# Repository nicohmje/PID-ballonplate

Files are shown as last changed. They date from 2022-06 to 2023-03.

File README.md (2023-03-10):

# Using a PID algo and Computer Vision to stabilize a ping-pong ball on a moving plane

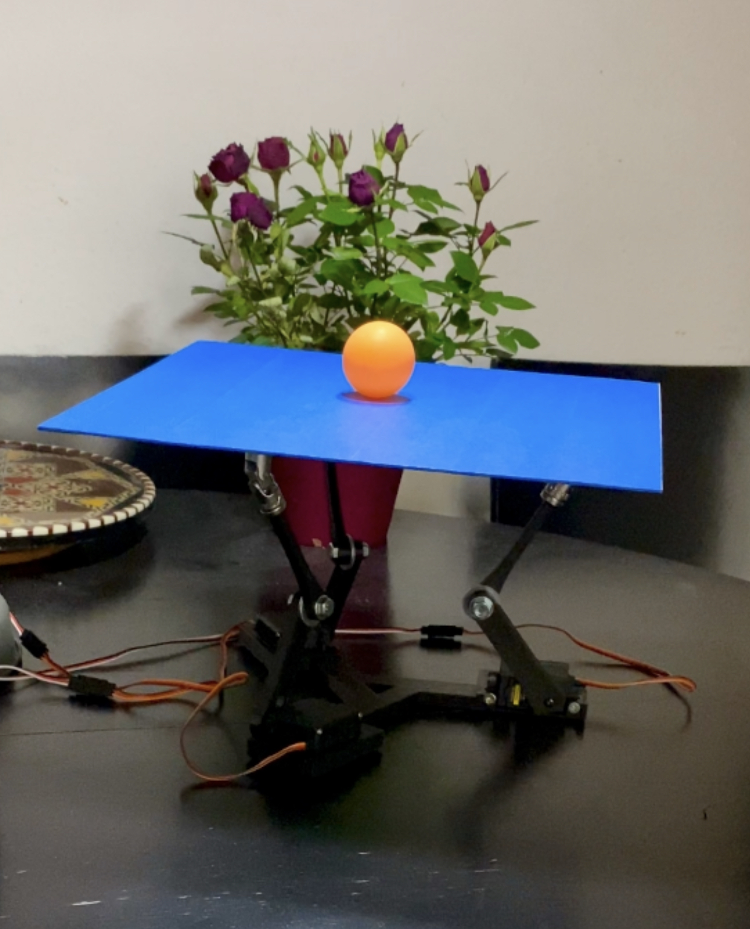
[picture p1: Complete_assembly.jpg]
the complete assembly


A relatively straightforward project using a Raspberry Pi, three servos and a 3D printed structure.

[SEE IT IN ACTION!](https://www.reddit.com/r/3Dprinting/comments/vbh1qf/3d_printed_all_the_parts_almost_for_this_fun/)

## Principle behind the project: 

1. A Pi camera tracks the position of the ball, using OpenCV. A mask is first applied separating the orange color of the ball from the rest. The mask is then eroded twice, blurred, and finally a 'smallest enclosing circle' command returns the radius and the center position.

2. This information is then filtered by radius. If it is part of the range of radii that the ball is expected to have, the program calculates the error between the position of the ball and the center of the plate. Three errors total are calculated, one for each servos' line of action.

3. These three errors are then input in the three PID Controllers, including past errors and past derivatives. The PID Controllers then output a change of angle for each servo, which is first normalized against computing time to account for small variations, and then sent using AdaFruit's servo library to the motors. 

## Improvements / Failures

My current platform is unstable at best, and requires constant recalibration (Done through the GUI); a more stable platform could be obtained with a better interface between the arms. Ball bearings could be used to further smoothen the motion of the platform, and more drastically three more servos could be added for a full on Stewart platform. At this scale however with this level of precision, the current platform is suitable enough. 

One could also use Dynamixel Servos for a more accurate position control, although this would significantly increase the price of the whole assembly. 

## Parts list : 

- Raspberry Pi 4b 8 gb
- Pi Camera V2
- Adafruit Camera cable extension
- Three DIYMORE Full metal servos
- Waveshare Servo HAT
- Pimoroni Fan Shim
- Three Dexter Cardan Joints (Universal joints)

The rest of the parts are 3D printed. 

Part selection really doesn't matter that much apart from the RPi and the PiCamera. Use what is available to you for a fair price, and adapt the parts to your needs. 

## Want to replicate this project yourself ? 

Great idea! If you need any help, feel free to shoot me a message on reddit (/u/parisiancyclist) or Instagram (@nicohmje). You can also directly contact me through GitHub. 

The STL Files folder includes the necessary parts for this project. These should be adapted to your parts and specific setup, and should only serve as a reference. The 3MF Files folder includes the prototypes too, if you want a deeper, in-depth look at the projects evolution.

Happy building!

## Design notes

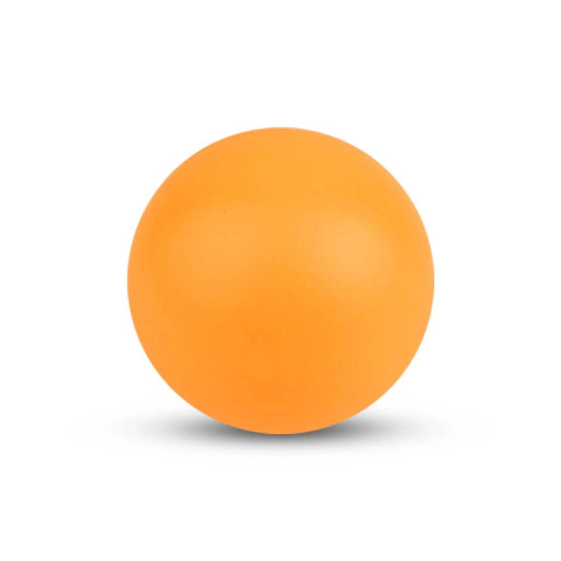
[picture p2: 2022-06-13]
ping-pong.jpg

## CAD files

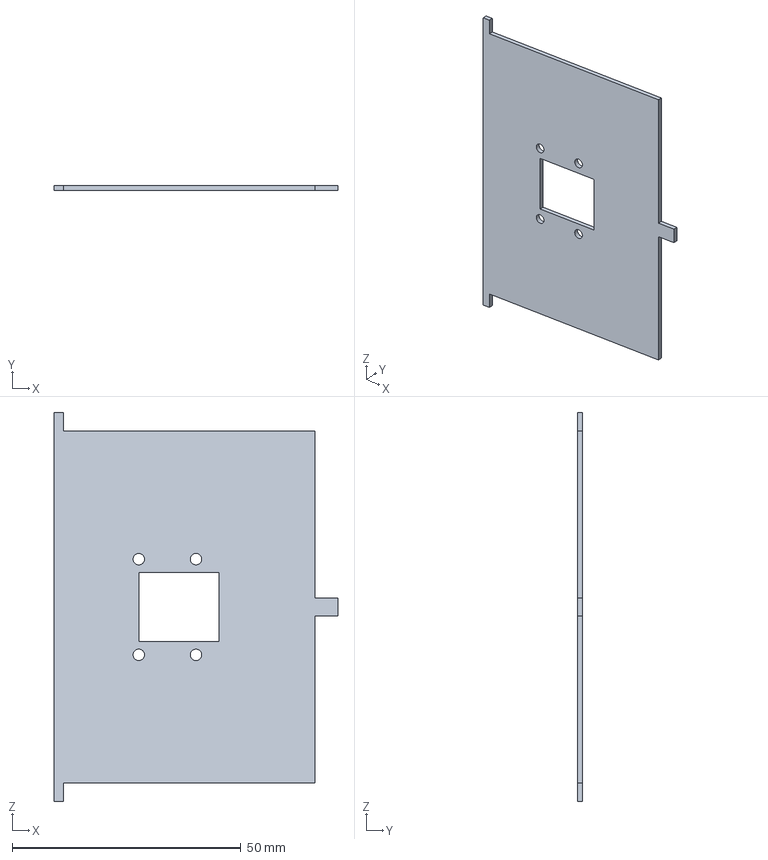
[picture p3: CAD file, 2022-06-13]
3MF Files/picamera_test2.3MF
62.0 x 1.20 x 85.0 mm

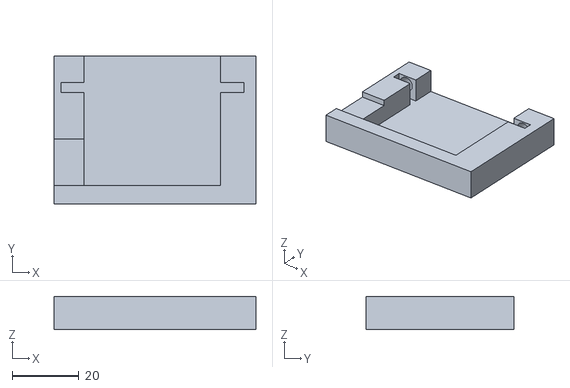
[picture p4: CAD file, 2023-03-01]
STL_Files/Servo_bracket_fit_test.stl
60.7 x 44.5 x 10.0

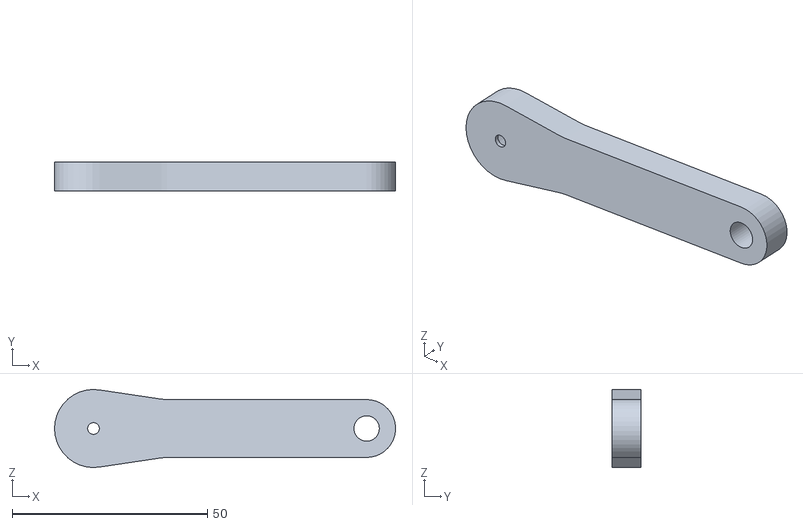
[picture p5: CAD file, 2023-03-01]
STL_Files/Arm1.STL
87.4 x 7.50 x 20.0

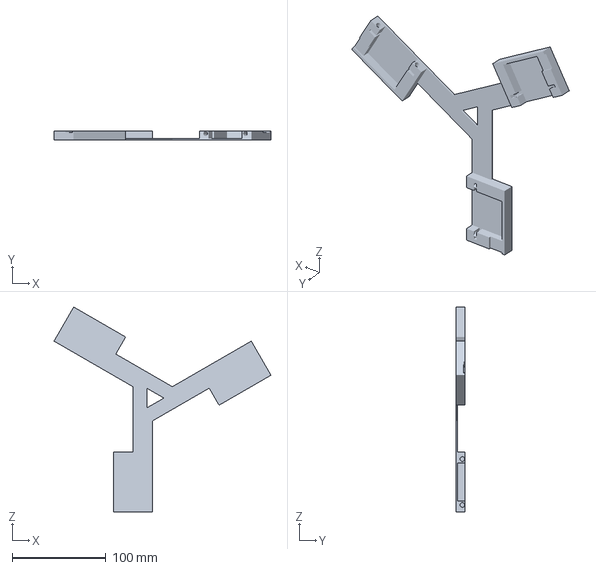
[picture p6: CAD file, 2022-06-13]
3MF Files/Base_proto1.3MF
231.4 x 10.0 x 218.6 mm

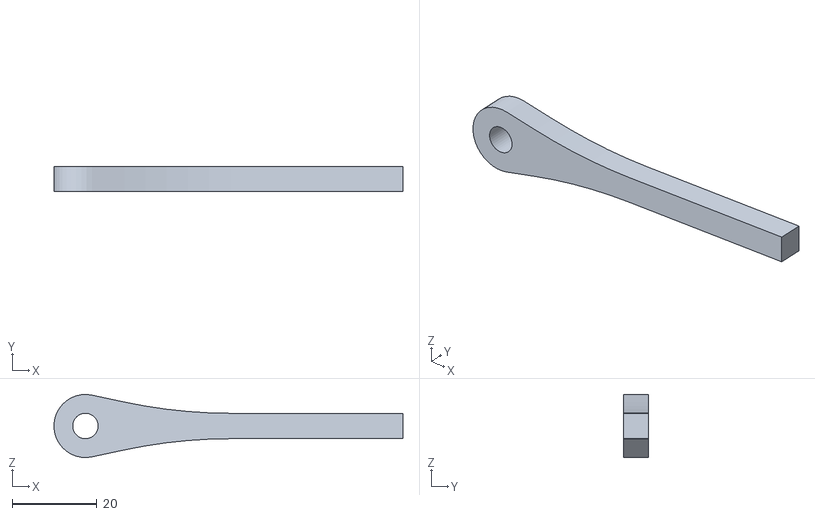
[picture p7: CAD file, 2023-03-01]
STL_Files/Arm2.stl
82.4 x 5.90 x 14.9

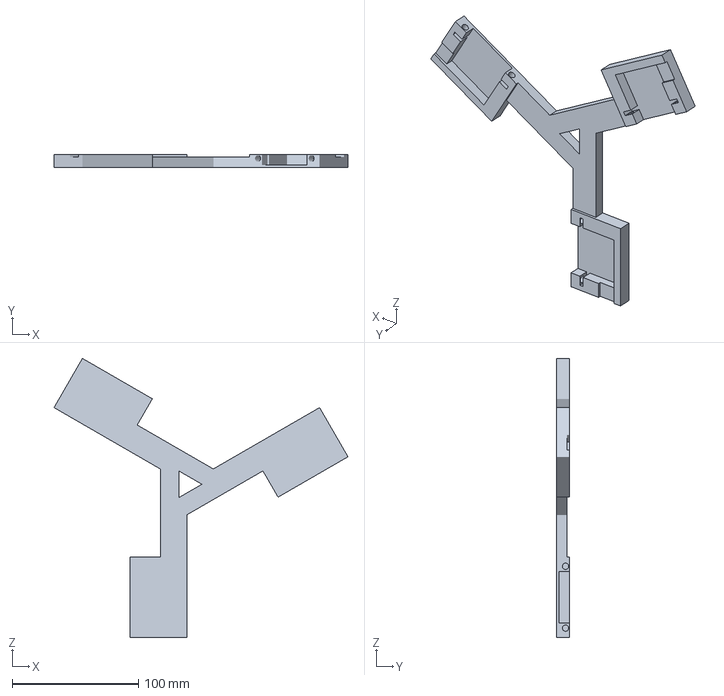
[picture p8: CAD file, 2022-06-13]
3MF Files/Base_proto2.3MF
232.9 x 10.0 x 221.2 mm

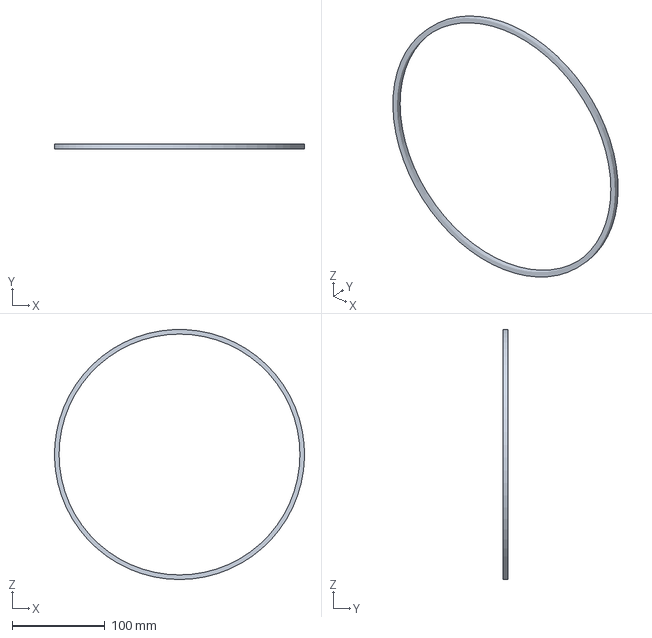
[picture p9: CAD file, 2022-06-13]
3MF Files/stencil.3MF
269.9 x 5.00 x 270.0 mm

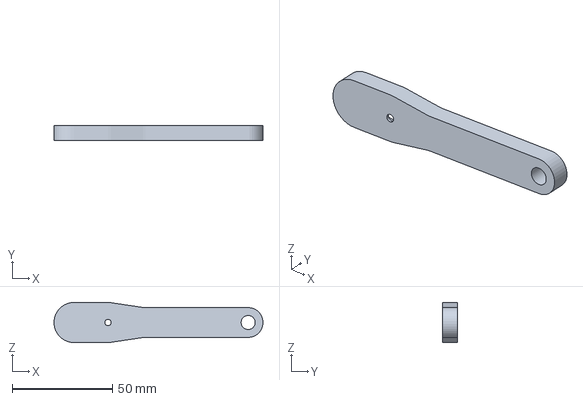
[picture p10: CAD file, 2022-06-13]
3MF Files/Arm_proto2.3MF
104.4 x 7.50 x 20.0 mm

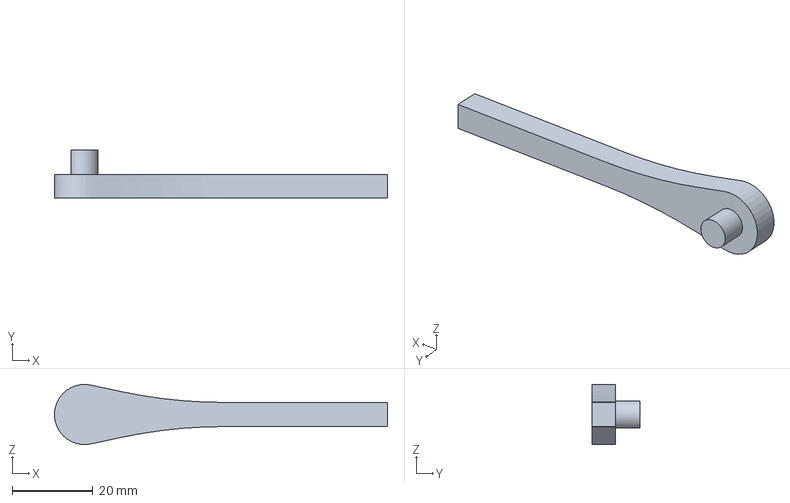
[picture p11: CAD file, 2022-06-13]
3MF Files/Arm2_proto2 3.3MF
82.4 x 12.0 x 14.9 mm

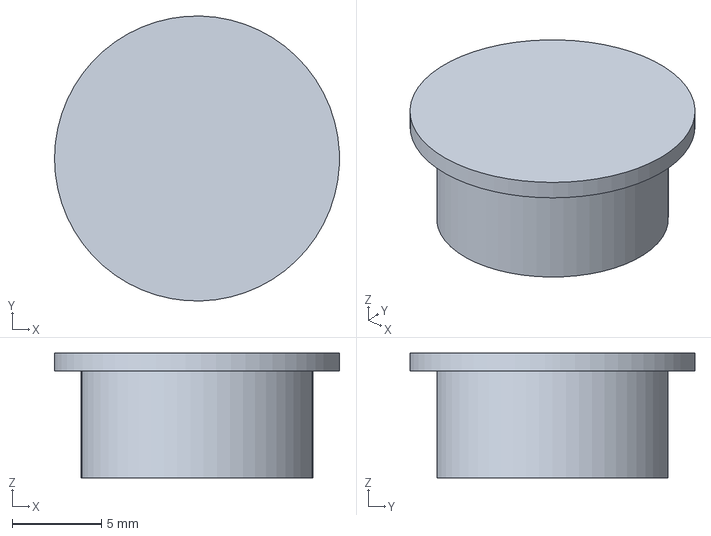
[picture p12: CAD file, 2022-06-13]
3MF Files/coupler.3MF
16.0 x 16.0 x 7.00 mm

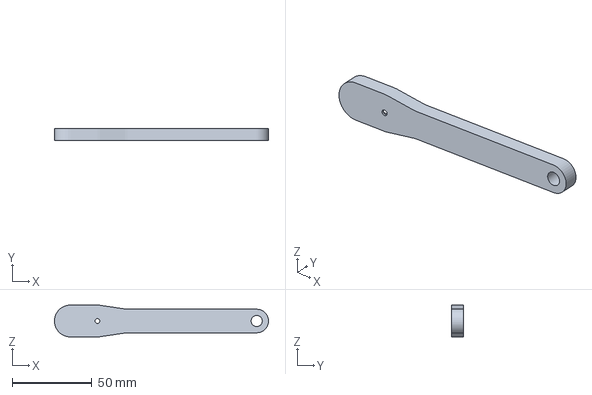
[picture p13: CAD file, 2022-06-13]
3MF Files/Arm_proto1.3MF
134.4 x 7.50 x 20.0 mm

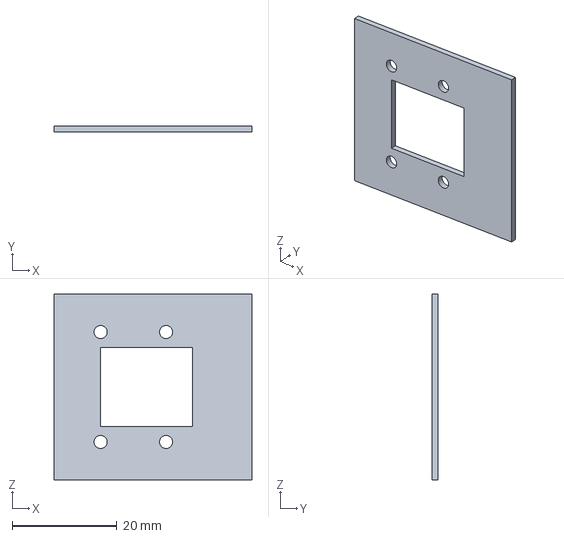
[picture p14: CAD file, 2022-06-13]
3MF Files/picamera_test.3MF
37.8 x 1.20 x 35.5 mm

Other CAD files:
3MF Files/Servo_bracket_proto2.3MF
STL_Files/Base.stl
3MF Files/Arm_proto3_1.3MF
3MF Files/Arm_proto3_2.3MF
3MF Files/Arm2_proto2 2.3MF
3MF Files/Arm_proto3_3.3MF
3MF Files/Arm2_proto1.3MF
3MF Files/Arm2_proto2.3MF
3MF Files/Arm2_proto3.3MF
3MF Files/PLATEAU.3MF
3MF Files/Servo_bracket_proto1.3MF
3MF Files/test_link.3MF

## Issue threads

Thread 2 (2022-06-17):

what is the model of the servo you used?

obstaclecourse, 2022-06-17:
thanks for the share!
in evaluating gathering the parts to make this, what model servo did you get from diymore and what's it's voltage?

nicohmje, 2023-01-14:
This is the amazon link to the servos I used : https://www.amazon.fr/dp/B09WQYPP17/
The model should not matter much.

Closed 2023-01-14.

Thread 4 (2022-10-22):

Just a question

915-Narita-Andrei, 2022-10-22:
Hello! First of all great job! I was very excited about your project and I also wanted to try it out. Please, could you send me the links of what you bought for this project? Especially for Three DIYMORE Full metal servos, Waveshare Servo HAT, Three Dexter Cardan Joints (Universal joints). I will be very grateful to you! Many thanks and keep up the good work!

nicohmje, 2022-10-22:
Hello, glad to hear you’re talking on this project! As for product links, if you’re not in France it wouldn’t be a good deal. The servos and cardan joints are the most generic thing ever, you should just look locally for something equivalent! The servo HAT was also something I bought because it was available in a shop near me. Here are the product links if you want the specs: Waveshare Servo Driver Hat Expansion Board Compatible with Raspberry Pi 12-Bit I2C Controlled Straight Pinheader Up to 16-Channel Servo/PWM Outputsamazon.frdiymore 6 pièces Servomoteur numérique à Engrenages en métal Version améliorée Servo de Couple à Grande Vitesse en cuivre Complet pour RC Hélicoptère Avion Voiture Bateau Robot Contrôleuramazon.frhttps://www.leroymerlin.fr/produits/outillage/outillage-a-main/cle/douille/cardan-chrome-vanadium-dexter-diam-15-mm-65996021.htmlLet me know if you need any other information! Cheers,Nicolas H. Sent from my iPhoneOn 22 Oct 2022, at 13:38, Andrei Narita ***@***.***> wrote:
Hello! First of all great job! I was very excited about your project and I also wanted to try it out. Please, could you send me the links of what you bought for this project? Especially for Three DIYMORE Full metal servos, Waveshare Servo HAT, Three Dexter Cardan Joints (Universal joints). I will be very gratefull to you! Many thanks and keep up the good work!

—Reply to this email directly, view it on GitHub, or unsubscribe.You are receiving this because you are subscribed to this thread.Message ID: ***@***.***>

Closed 2023-01-14.

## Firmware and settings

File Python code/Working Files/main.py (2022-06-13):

import numpy as np 
import cv2 as cv
import time
import tkinter as tk
from adafruit_servokit import ServoKit

#Initialize the three servos
kit = ServoKit(channels = 16)
kit.servo[0].set_pulse_width_range(500, 2500) #Very important
kit.servo[1].set_pulse_width_range(500, 2500) #Very important
kit.servo[2].set_pulse_width_range(500, 2500) #Very important

#Center coordinates
center_x = 250
center_y = 250  

prevX = 0
prevY = 0 

#Min and max angles of each motor
min_motor = np.array([85,85,77])
max_motor = np.array([175,175,165])

#Sets the angle of the motors to the chosen values
def set_angle():
    global initial_angle
    initial_angle[0] = e0.get()
    initial_angle[1] = e1.get()
    initial_angle[2] = e2.get()
    initialPos()

initial_angle = np.array([124,120,111]) #These depend on how level the surface is

#Initial position of the motors
def initialPos():
    kit.servo[0].angle = int(e0.get())
    kit.servo[1].angle = int(e1.get())
    kit.servo[2].angle = int(e2.get())

#Initialize the capture 
cap = cv.VideoCapture(0)

#Moves the motor according to the instructions given by the PID
def move_motors(pid):
    for i in np.arange(0,3,1):
        angle = initial_angle[i] - (pid[i]/150.0 * 20)
        angle = np.floor(angle)
        if angle > max_motor[i]:
            print("angle limit high")
            angle = max_motor[i]
        if angle < min_motor[i]:
            print("angle limit low")
            angle = min_motor[i]
        kit.servo[i].angle = angle 

#Finds the ball's center
def ballFinder():
    ret, frame = cap.read()
    result = (0,0)
    if ret:
        frame = frame[:, 93:550, :]
        hsv = cv.cvtColor(frame, cv.COLOR_BGR2HSV)
        lower_value = np.array([00,80,100])
        higher_value = np.array([50,255,255])
        mask = cv.inRange(hsv, lower_value, higher_value)
        mask = cv.blur(mask,(6,6))                        
        mask = cv.erode(mask, None, iterations=2)         
        mask = cv.dilate(mask, None, iterations=2)        
        contours, _ = cv.findContours(mask, cv.RETR_TREE, cv.CHAIN_APPROX_SIMPLE)
        for cnt in contours:
            area = cv.contourArea(cnt)
            if area > 1500:
                (x,y), radius = cv.minEnclosingCircle(cnt)
                x = int(x)
                y = 480 - int(y) #In images, y=0 is on top, not on the bottom 
                radius = int(radius)
                if radius > 20:
                    result = (x,y)
    return(result)

#This allows you to properly place the plate beneath the camera
def CenterCalibration():
    for i in np.arange(0,150):
        ret, frame = cap.read()
        if ret:
            frame = frame[:,93:550,:]
            cv.circle(frame,(center_x,center_y),3,[255,130,130],3)
            cv.imshow("Calibration", frame)
            cv.waitKey(1)
        else:
            pass
           
        
started = False
#GUI and looping
def start_program():
    global started,i
    set_values()
    reset_values()
    if started:
        start["text"] = "Start"
        started = False
    else:
        start["text"] = "Stop"
        started = True

errors = np.zeros(3)
pasterrors = np.zeros(3)
#Calculates the error for each line of action of each servo
def get_errors(x,y):
    global center_x, center_y, errors, pasterrors
    print(center_x, center_y)
    pasterrors = np.copy(errors)
    errors[0] = y - center_y  
    errors[1] = (np.sqrt(3)*(x-center_x) + (center_y - y))/2.0
    errors[2] = (np.sqrt(3)*(center_x - x) + (center_y - y))/2.
    #errors[abs(errors - pasterrors) > 40] = pasterrors[abs(errors - pasterrors) > 40]
    #print(abs(errors - pasterrors))
    print(errors[0])

lastderivative = 0 
lastlastderivative = 0 
integral = 0
derivative = 0 
pid = 0
#Calculates the PID and normalizes it based on computation time 
def pid_control(compT):
    global errors, pasterrors
    global lastderivative, lastlastderivative, derivative
    global Kp, Ki, Kd, Ka
    global integral
    global lastpid
    global computation_time
    #output == Kp * error + Ki * integral + Kd * derivative 
    global pid 
    if np.all(errors > 10):
        integral += errors * 0.5 
    else:
        integral = 0
    Kd_normalized = np.copy(Kd) / (compT/np.mean(computation_time))
    Ka_normalized = np.copy(Ka) * (compT/np.mean(computation_time))
    Kp_normalized = np.copy(Kp)
    Kp_normalized[np.abs(errors) < 20] = Kp_normalized[np.abs(errors) < 20] * 0.5
    lastlastderivative = np.copy(lastderivative)
    lastderivative = np.copy(derivative)
    derivative = (errors - pasterrors)
    #print("SUM",np.sum(abs(derivative)))
    if np.sum(abs(derivative)) < 10:
        Kd_normalized = Kd_normalized *  (0.1*(np.sum(abs(derivative))))
    elif np.sum(abs(derivative)) > 20:
        Kd_normalized = Kd_normalized * 1.1
    if np.all(np.abs(derivative) < 0.5):
        Kd_normalized = 0
    lastpid = pid
    pid = Kp_normalized * errors + Ki * integral  + Kd_normalized * (((5*derivative) + (3*lastderivative) + (2*lastlastderivative))/10.0) + Ka_normalized * (((derivative - lastderivative) + (lastderivative - lastlastderivative))/2.0) 
    return pid 


Kp = np.zeros(3)
Kd = np.zeros(3)
Ka = np.zeros(3)
Ki = np.zeros(3)

#Resets the values, if the ball leaves the plate
def reset_values():
    global derivative, lastderivative, lastlastderivative, i
    global pasterrors, errors, pid
    derivative = 0
    lastderivative = 0
    lastlastderivative = 0 
    pid = 0
    i = 0
    print('successfully reset all values')

#sets the coefficients 
def set_values():
    global Kp, Ki, Kd, Ka
    i = int(motor_selector.get())
    if i == 3:  
        Kp[:] = p_slider.get() / 10.0 
        Ki[:] = i_slider.get() / 10.0
        Kd[:] = d_slider.get()
        Ka[:] = a_slider.get()
    else:
        Kp[i] = p_slider.get() / 10.0 
        Ki[i] = i_slider.get() / 10.0
        Kd[i] = d_slider.get()
        Ka[i] = a_slider.get()
    print(Kp, Ki, Kd, Ka)

t = 0 
#Refreshes the 'ball position' graph
def refresh(x, y):
    global t
    graphWindow.deiconify()
    graphCanvas.create_oval(x,y,x,y, fill="#b20000", width=4)
    graphCanvas.create_line(0,240,480,240, fill="#0069b5", width=2)
    graphCanvas.create_line(240,0,240,480, fill="#0069b5", width=2)
    if t >= 480:
        t = 0
        graphCanvas.delete("all")
        graphCanvas.create_line(0,240,480,240, fill="#0069b5", width=2)
        graphCanvas.create_line(240,0,240,480, fill="#0069b5", width=2)
        graphCanvas.create_oval(x,y,x+1,y, fill="#b20000")
    t += 4

computation_time = []
#Main loop
def main():
    global prevX, prevY, computation_time
    global center_x, center_y
    start_time = time.time()
    if started:
        x, y = ballFinder()
        #print("posiiton", x,y)
        if x != y != 0: 
            detected = True
            get_errors(x,y)
            compT = (time.time() - start_time)
            computation_time.append(compT)
            pid = pid_control(compT)  
            #print(pid[0])
            #print(compT / np.mean(computation_time))

            move_motors(pid) 
            prevX = x
            prevY = y
        else:
            initialPos()        
        refresh(x, y)
    lmain.after(1,main)

    
#GUI PART 

window = tk.Tk()
window.geometry("820x500")
window.title("Test ?")

p_slider = tk.Scale(window,  from_=0, to=15, orient="horizontal", label="Proportionnal", length=500, tickinterval=2.5, resolution=0.1)
p_slider.set(3)
p_slider.pack()
i_slider = tk.Scale(window,  from_=0, to=1, orient="horizontal", label="Integral", length=500, tickinterval=0.25, resolution=0.005)
i_slider.set(0)
i_slider.pack()
d_slider = tk.Scale(window,  from_=0, to=10, orient="horizontal", label="Derivative", length=500, tickinterval=10, resolution=0.1)
d_slider.set(6.2)
d_slider.pack()
a_slider = tk.Scale(window,  from_=0, to=10, orient="horizontal", label="Double Derivative", length=500, tickinterval=10, resolution=0.1)
a_slider.set(5.6)
a_slider.pack()

p_slider.place(x=250, y= 0)
i_slider.place(x=250, y= 100)
d_slider.place(x=250, y= 200)
a_slider.place(x=250, y= 300)

tk.Label(window, text="Motor0").place(x=00,y=20)
tk.Label(window, text="Motor1").place(x=00,y=50)
tk.Label(window, text="Motor2").place(x=00,y=80)


lmain = tk.Label(window)
lmain.pack()

graphWindow = tk.Toplevel(window)
graphWindow.title('Ball position')
graphCanvas = tk.Canvas(graphWindow,width=480,height=480)
graphCanvas.pack()

motor0 = tk.StringVar(window)
motor1 = tk.StringVar(window)
motor2 = tk.StringVar(window)
motor_select = tk.StringVar(window)
motor0.set(str(initial_angle[0]))
motor1.set(str(initial_angle[1]))
motor2.set(str(initial_angle[2]))
motor_select.set("3")

e0 = tk.Spinbox(window, from_=100, to=200, command=set_angle, width=3, textvariable=motor0)
e1 = tk.Spinbox(window, from_=100, to=200, command=set_angle, width=3, textvariable=motor1)
e2 = tk.Spinbox(window, from_=100, to=200, command=set_angle, width=3, textvariable=motor2)

motor_selector = tk.Spinbox(window, from_=0, to=3, width=2, textvariable=motor_select)

motor_selector.place(x=100, y= 100)

e0.place(x=50, y=20)
e1.place(x=50, y = 50 )
e2.place(x=50, y = 80)



start = tk.Button(window, text="Start" ,command=start_program)
start.place(x=20, y=225)
Breset = tk.Button(window, text="Reset", command=reset_values)
Breset.place(x=20, y= 250)
set = tk.Button(window, text='set values', command=set_values)
set.place(x=400, y = 350 )
    
#END OF GUI

#Final order of operations : 
initialPos()
CenterCalibration()
cv.destroyAllWindows()
main()
window.mainloop()

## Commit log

2023-03-01 Create STL Files
2023-03-01 Add STL files
    [Arm1.STL, Arm2.stl, Base.stl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]
